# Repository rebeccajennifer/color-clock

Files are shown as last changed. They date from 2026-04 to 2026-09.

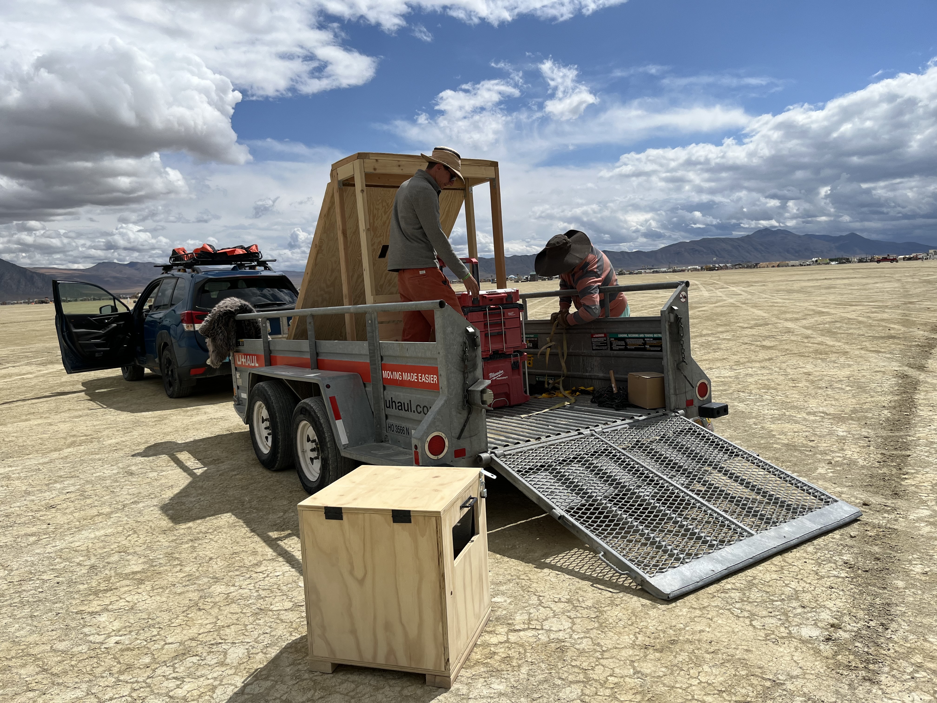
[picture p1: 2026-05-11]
docs/slide-decks/2026-05-05__engineering-talk/07__deployment__eng-talk/on-site-install__eng-talk/IMG_2247.jpeg

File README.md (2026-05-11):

# ColorClock

## Code Location

The code base is contained in the Arduino directory located at
[./sw/arduino/color-clock-driver](./sw/arduino/color-clock-driver).

## Hardware

The project was designed using an `MKR1010` Arduino board that
interfaces with a real time clock module to keep accurate time.

### Wiring Diagram



## Documentation

The blog about this project can be found
[here](http://rebeccarashkin.com/color-clock).

A slide deck outlining the hardware and software design:
[here](./docs/slide-decks/2026-05-05__engineering-talk/color-clock-design__20260508.pdf)

## Description

Version 1 of ColorClock was an art piece displayed at Burning Man in
2024. The piece was a minimalist lean-to shade structure, housing a
2.5 ft diameter light display at its core. Within, a bench invited
participants to rest just above the playa. The light display, crafted
with concentric circles, marked the current time, providing nuanced
granularity such as the hour and minute. A user-controllable central
light introduced an element of interactivity. With a control panel,
the participant could manage cycle time and spectrum hues, enhancing the
understanding of the piece. ColorClock, in its simplicity and
interactivity, prompts contemplation on the temporal interplay of light
against the expansive backdrop of the playa landscape.

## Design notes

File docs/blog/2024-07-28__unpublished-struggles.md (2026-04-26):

This weekend I'm finally at the point that I wanted to be *last* weekend. After spending almost all of last Saturday soldering I learned that powering the Arduino with 12 volts no bueno 😵 But I knew I had some LM7805s (5 volt linear regulators) somewhere. Then a series of unfortunate events ensued...

- Soldered it too close to where the Arduino was supposed to go
- Battled with desoldering, surrendered the part
- Soldered in a new voltage regulator
- Realized I soldered it in backward
- Added new wires to make it work
- Plugged in the wrong Arduino board because it had the same footprint
- Realized level shifter wasn't working
- Battled with desoldering the headers from the component
- Gave up and soldered on longer pins
- Wired everything and found the on board buttons weren't working when the lights were on
- Fried my Arduino board while debugging

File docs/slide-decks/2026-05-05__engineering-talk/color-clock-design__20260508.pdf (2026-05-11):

# ColorClock

## Tell time through color

Introduction
Color Foundations
System Overview
Time Controller
Light Display
User Interface
Circuit Board Evolution
Deployment
Final Thoughts

# Introduction

What is ColorClock?

_____________________________

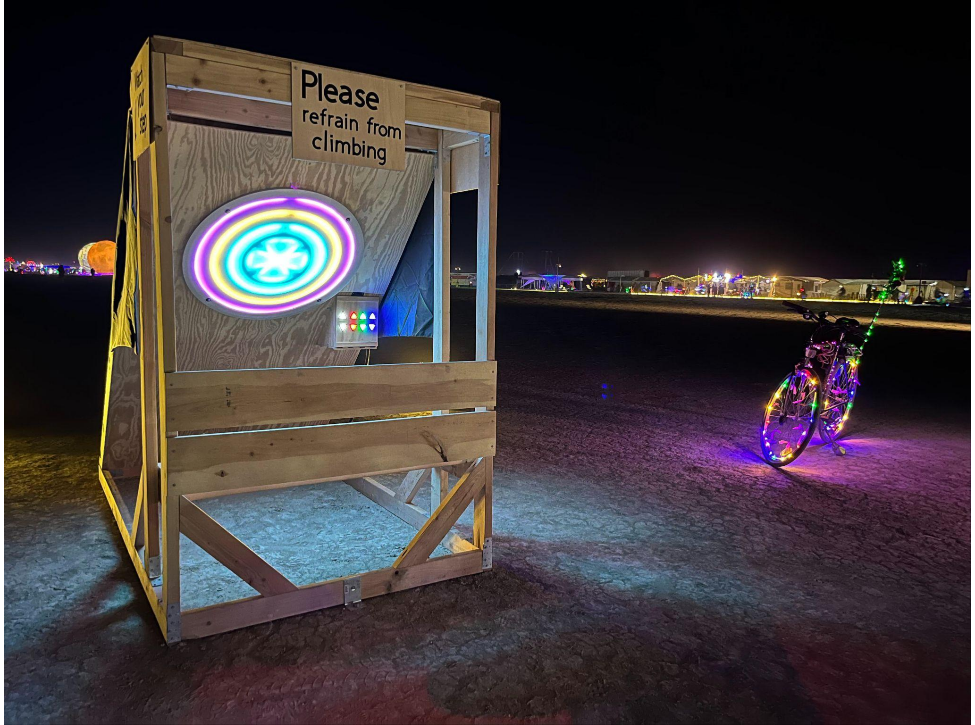
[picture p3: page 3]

## Software Prototype 2020

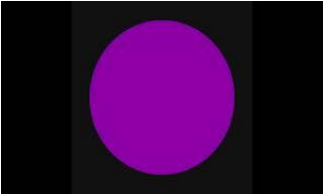
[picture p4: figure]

- | Built with | Processing:
Java-based language
for digital art
- Exercises color-time
mapping algorithm
- Cycle time: 6 seconds

## Module Prototyping 2022

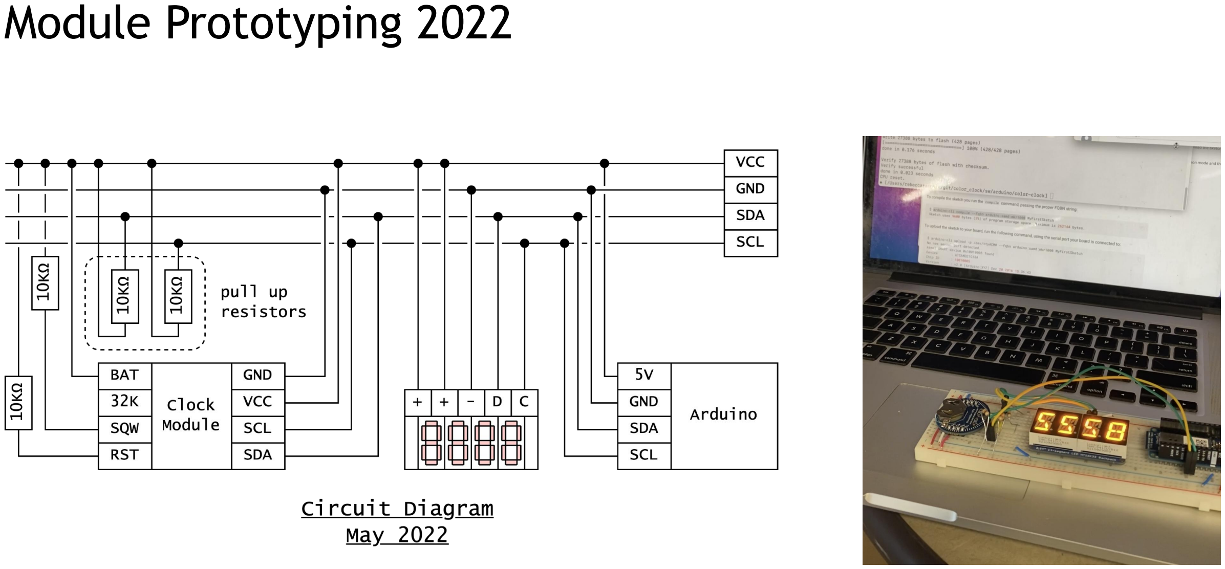
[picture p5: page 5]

Introduction
Color Foundations
System Overview
Time Controller
Light Display
User Interface
Circuit Board Evolution
Deployment
Final Thoughts

# Color Foundations

Mixing color with pigment
and light

_____________________________

## Pigment Primary Colors: Red, Yellow, Blue

## Light Primary Colors: Red, Green, Blue

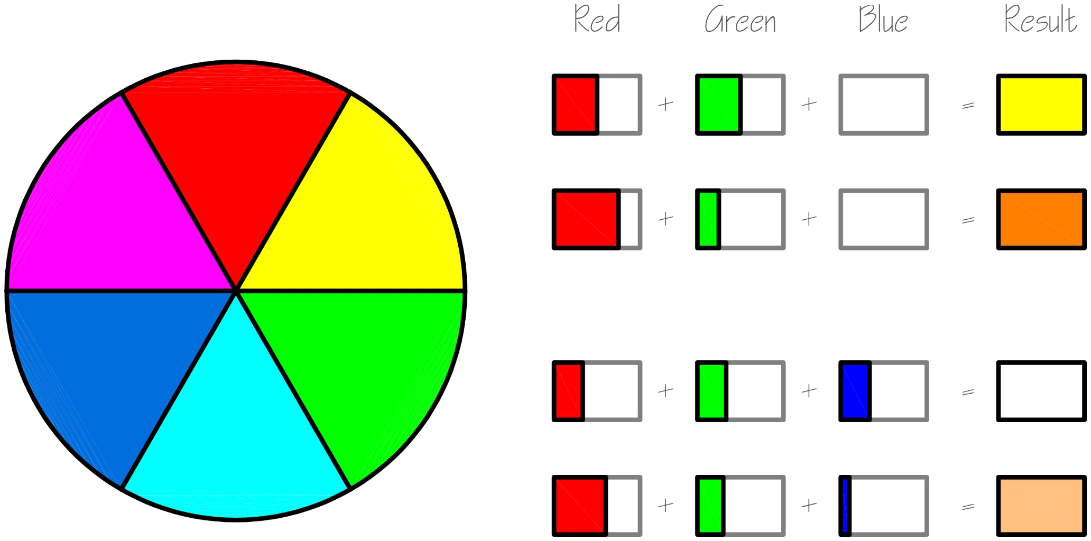
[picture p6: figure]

## Common Anode RGB LED - Light Orange = 4:2:1 R:G:B

Introduction
Color Foundations
System Overview
Time Controller
Light Display
User Interface
Circuit Board Evolution
Deployment
Final Thoughts

# System Overview

Top level design

_____________________________

## Light Display

## Use Case Diagram

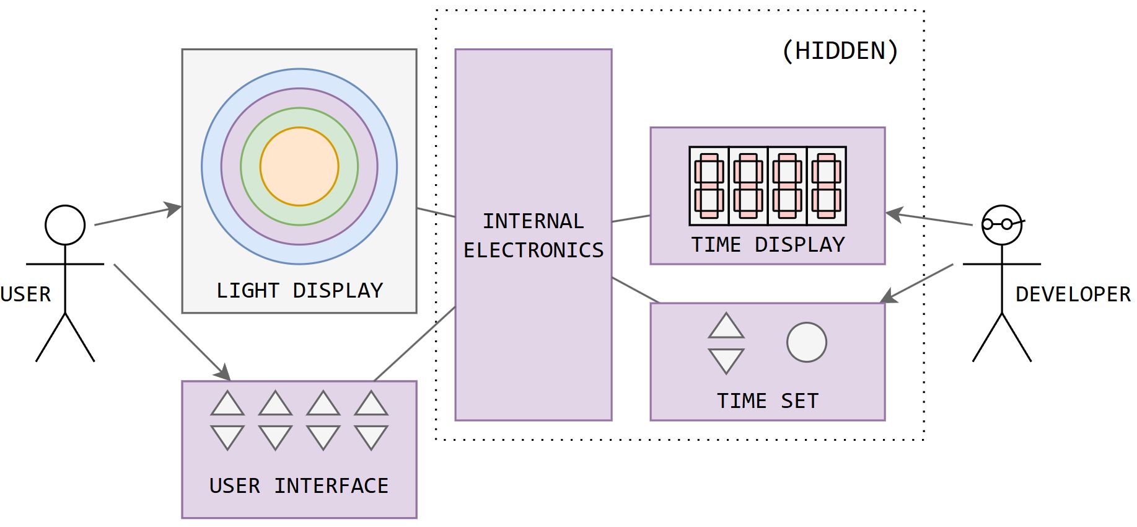
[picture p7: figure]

- User:
- Views light display
- Interacts with user
control interface
- Developer:
- Sets time
- Views time display
- Internal electronics
- I/O & control logic

## Top Level Hardware Design

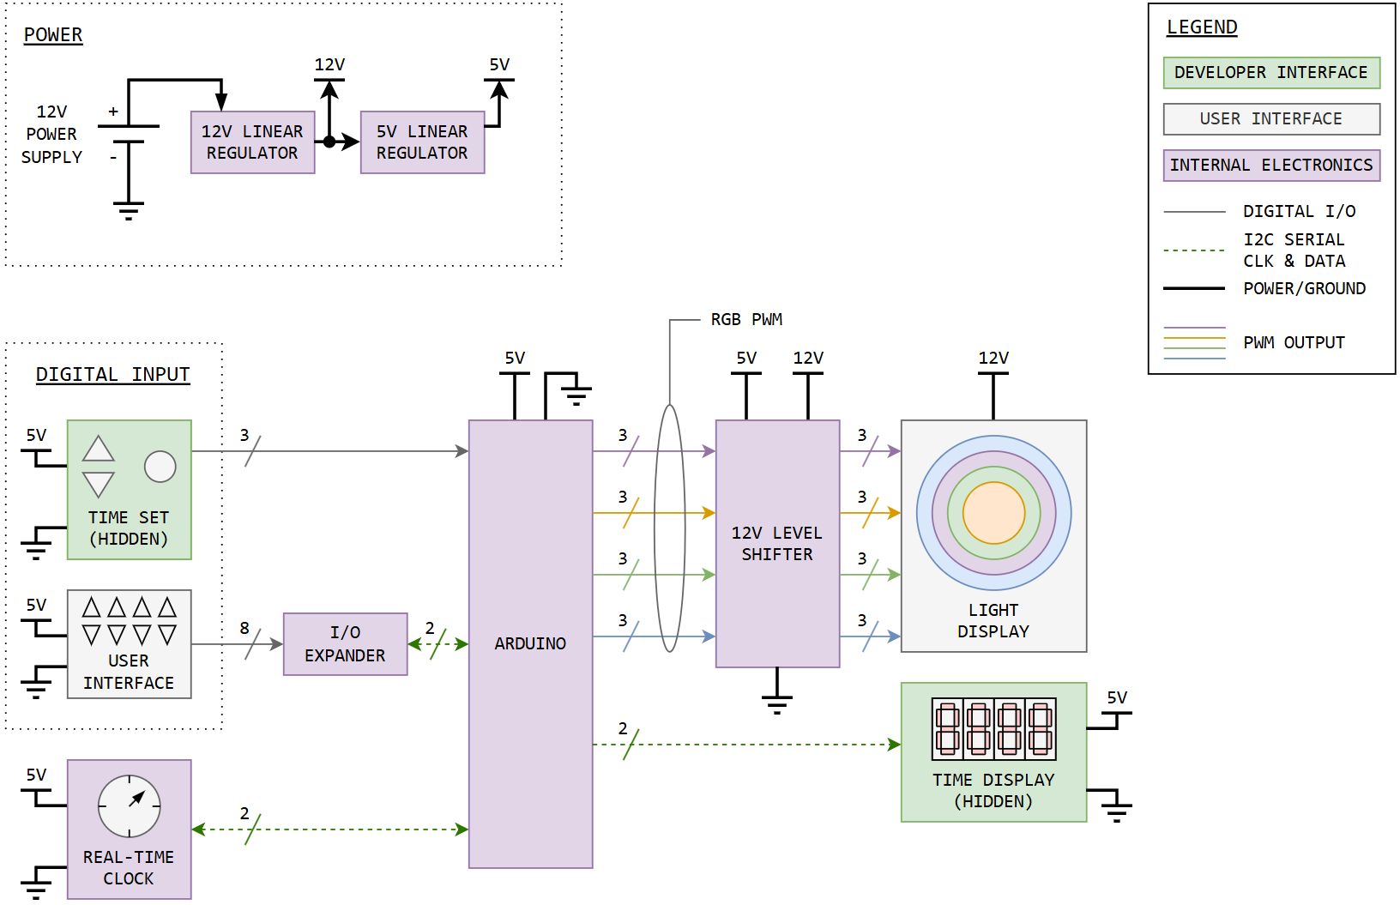
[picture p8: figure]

## Top Level Software Architecture

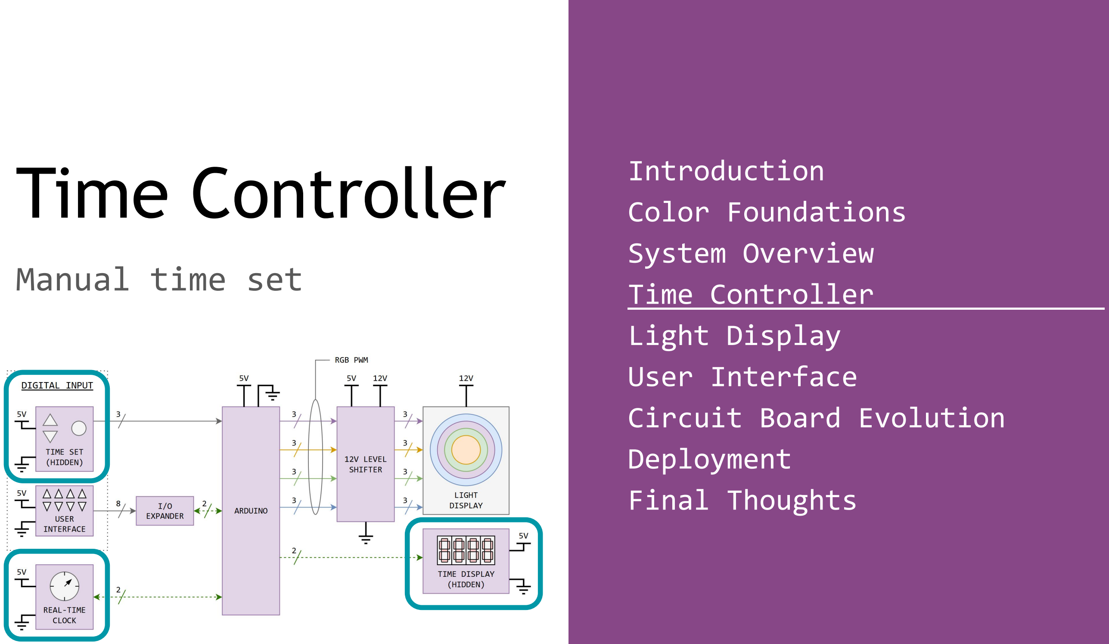
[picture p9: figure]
Introduction Color Foundations System Overview Time Controller Light Display User Interface Circuit Board Evolution Deployment Final Thoughts; Time Controller; Manual time set

## Time Controller Architecture

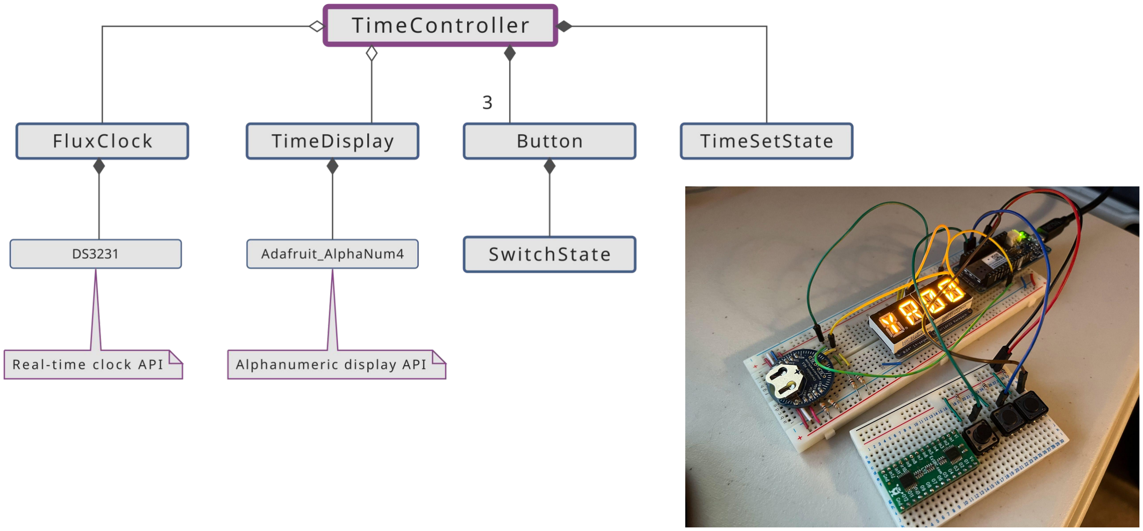
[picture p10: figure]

## State Diagrams

## Millisecond Granularity with Clock Module + System Time

- Real-time clock module - time resolution up to one second
- Millisecond precision is derived by combining:
- RTC time | (seconds)
- Arduino uptime (milliseconds since power-on)
- Hybrid approach enables higher resolution than the RTC alone
- Increased resolution -> supports smoother color transitions

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

_____________________________

## 4 ColorClocks; Color Shifts at Different Frequencies

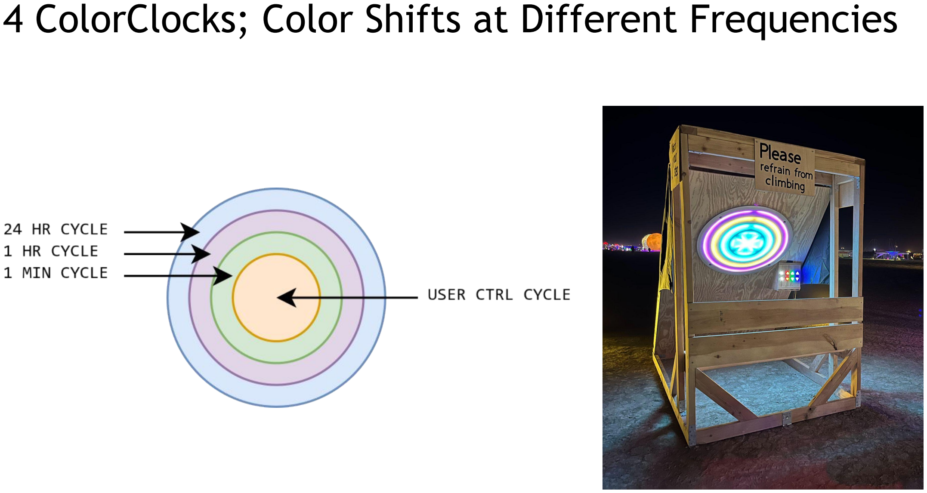
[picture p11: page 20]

## Level Shifter Scales Analog Output

- Input and output
reference voltages
- Used to scale a logic
level output, e.g. 3V to
12V
- Works as an amplifier in ColorClock

## Wiring Diagram Arduino to Level Shifter

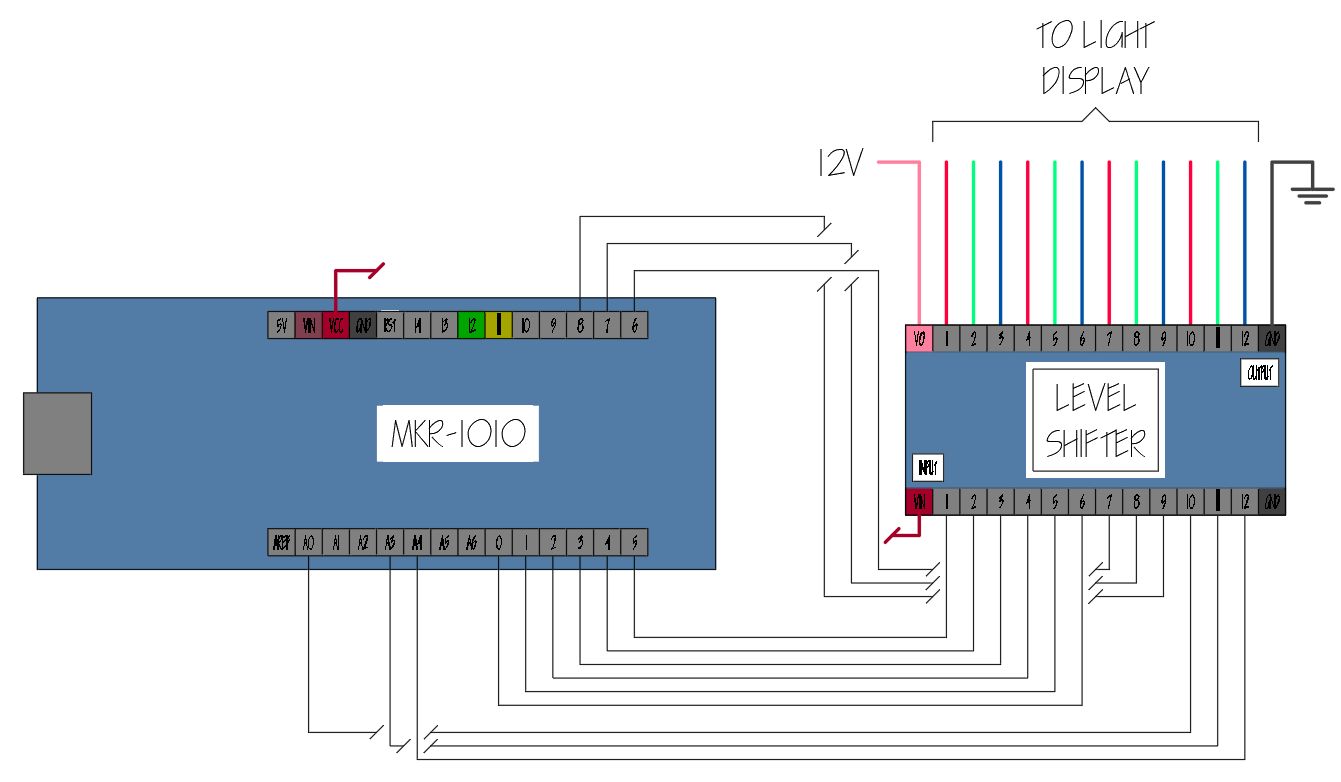
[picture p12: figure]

- Four ColorClock objects,
each with RGB from PWM
pins
- Microcontroller outputs
max 5V; LEDs require 12V
- Level shifter increases
output voltage from PWM
output pins

## ColorClock Class Diagram

## Colors Expressed as 24-Bit RGB Values

- Red, green, and blue
channels use intensity
values from 0–255
(0x00 → 0xFF hexadecimal)

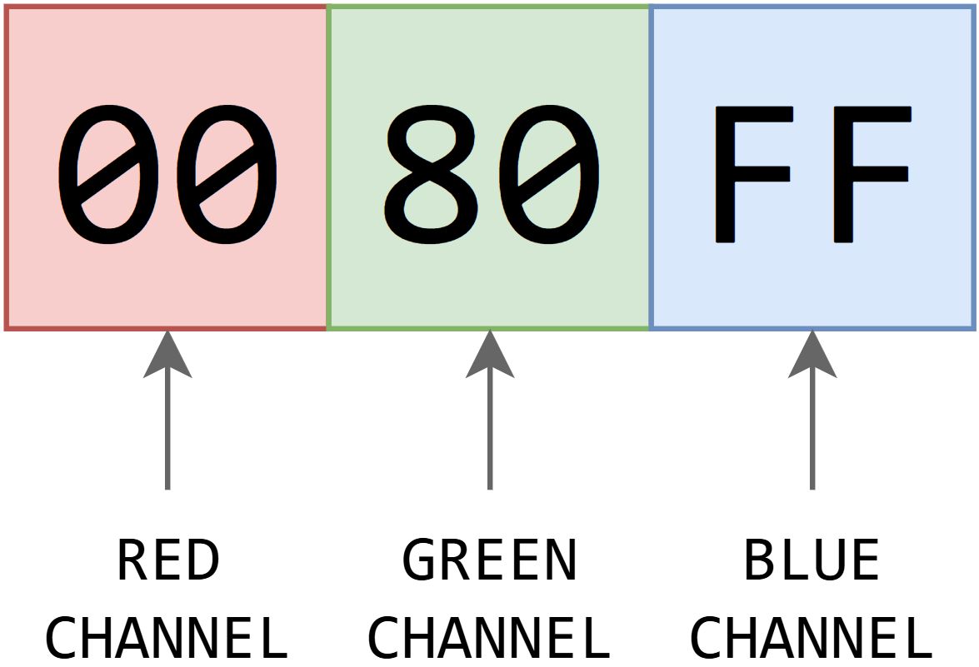
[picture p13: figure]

- PWM output interprets each channel value as a
fraction of full-scale
output (value / 255)

## Parallel Time-Color Mapping

- Two parallel arrays,
equal length
- One array stores colors
- One array stores the
corresponding times for
each color
color_selection | color_times
#FF0000 | 00:00

#FFFF00 | 04:00

#00FF00 | 08:00

#00FFFF | 12:00

#0000FF | 16:00

#FF00FF | 20:00

## Color Mapping Data Flow

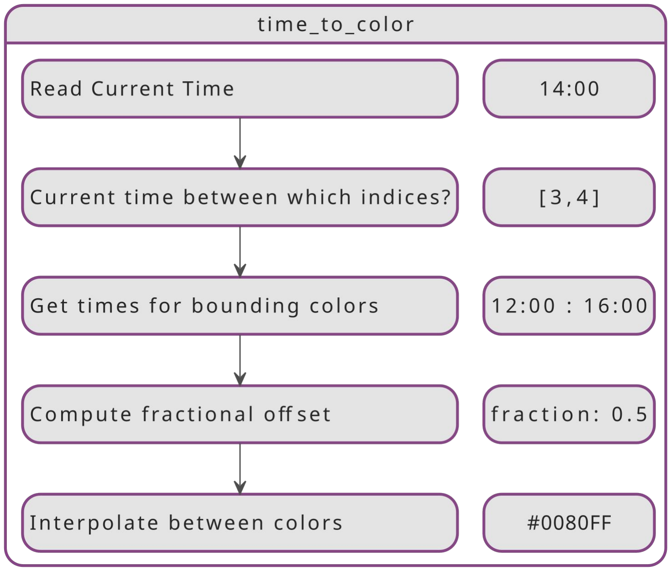
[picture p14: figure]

## Color Update Timing Testing

Color Updates Every Second | Color Updates Every Millisecond

Cycle Times: Top-6s, Middle-12s, Bottom-30s

## Light Display Construction

## Light Display Final Implementation

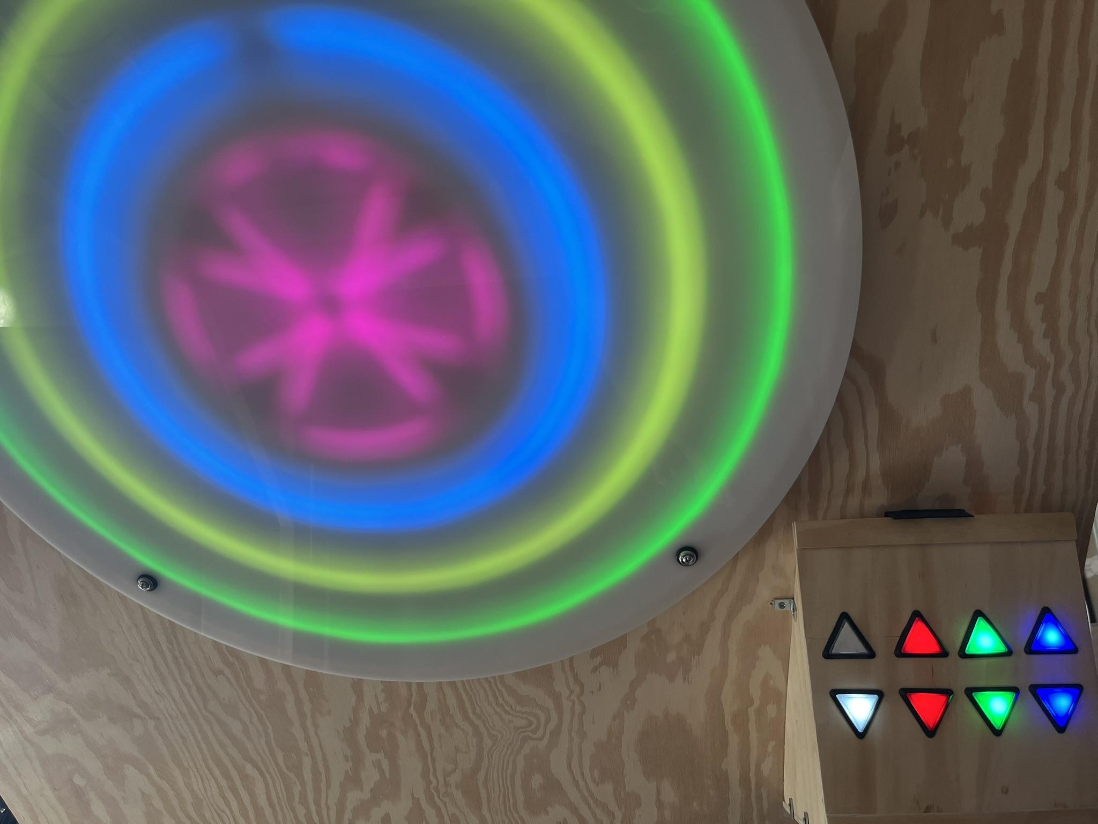
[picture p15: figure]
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

_____________________________

## User Input Control

Class Structure

## User Control Panel Prototyping

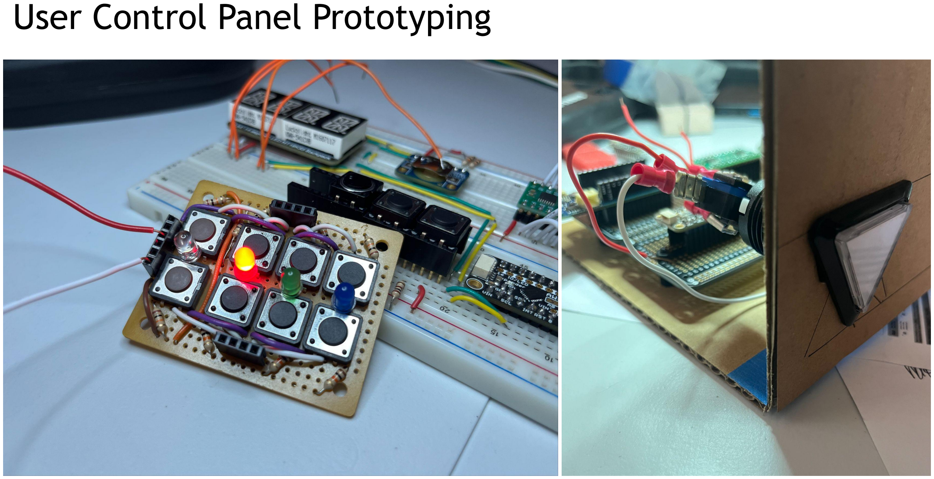
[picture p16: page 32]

## Final Implementation

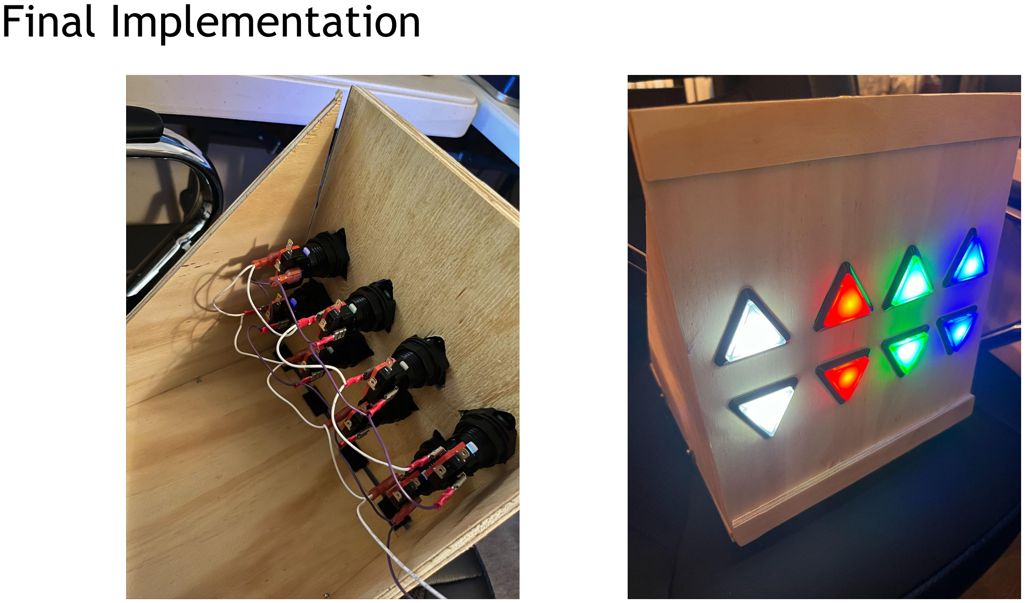
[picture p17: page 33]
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

# Circuit Board Evolution

From prototype to final
implementation

_____________________________

## Full Circuit Board Solderless Prototype

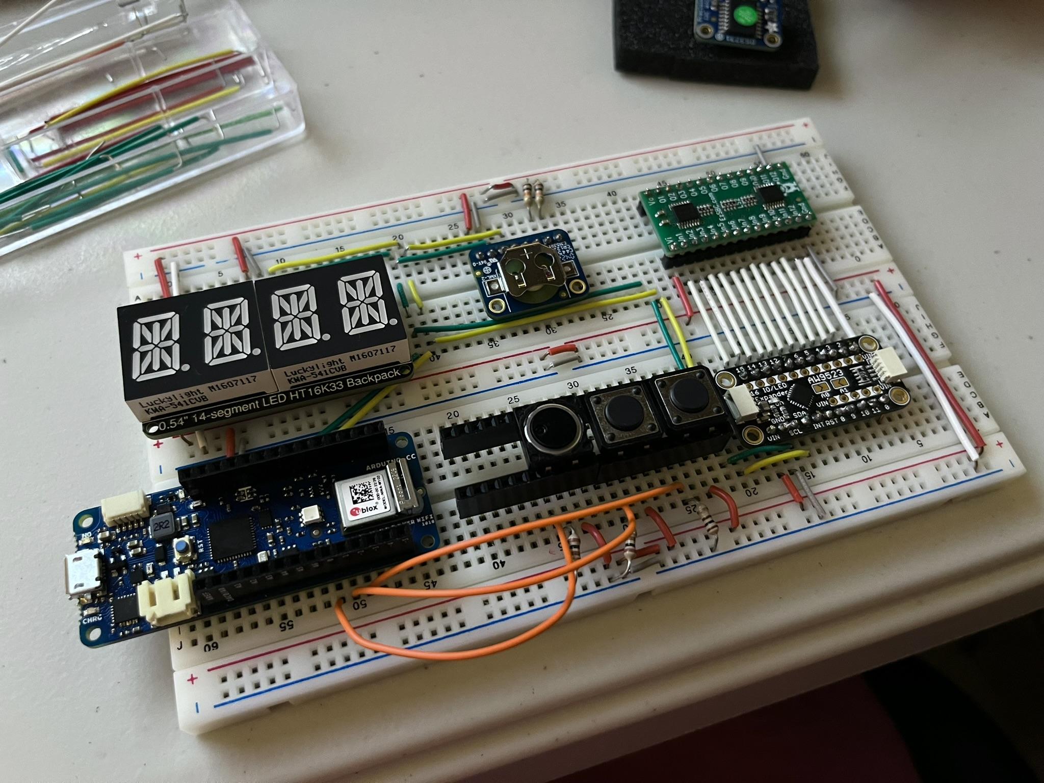
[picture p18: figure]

## Socketed Components for Rapid Replacement

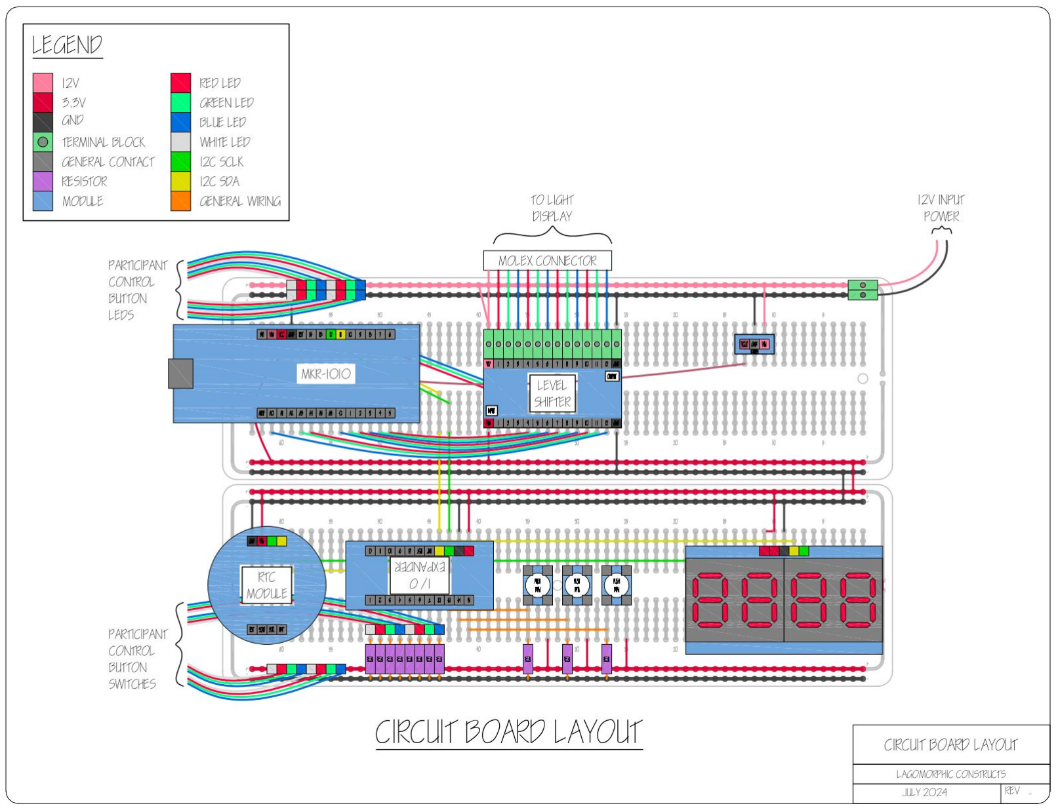
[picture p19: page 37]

## Final Implementation

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

_____________________________

# Infrastructure & Deployment

Structural implementation
and build

## Early Design Limitations

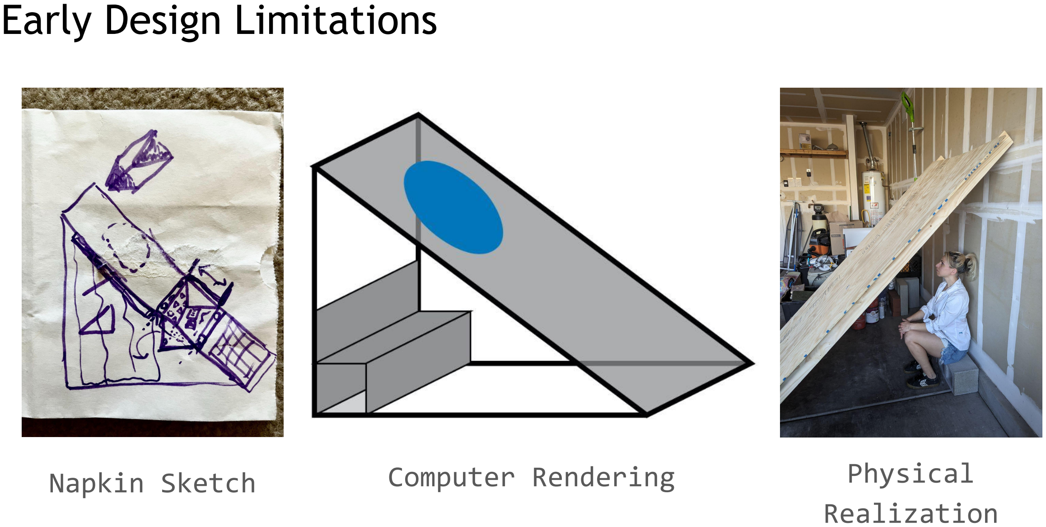
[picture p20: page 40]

Napkin Sketch | Physical Realization
Computer Rendering

## Extended Roof Design

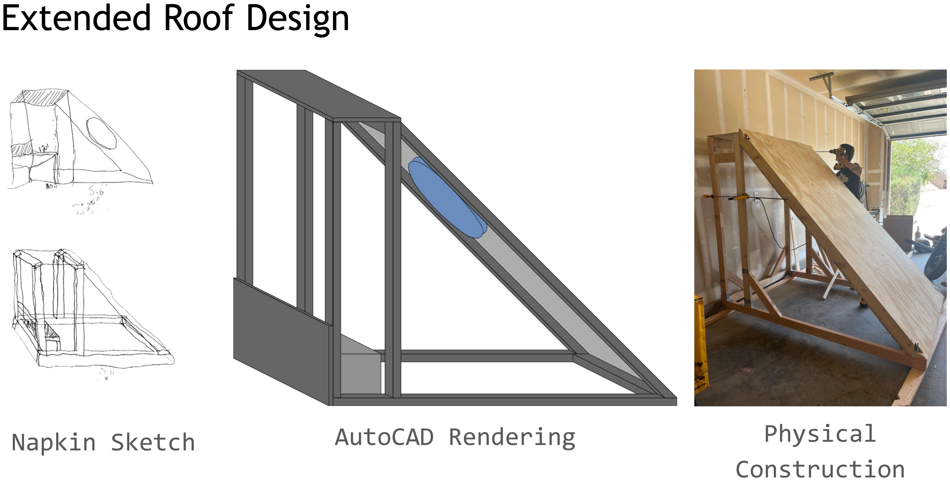
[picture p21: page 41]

Napkin Sketch | Physical Construction
AutoCAD Rendering

## Physical Assembly

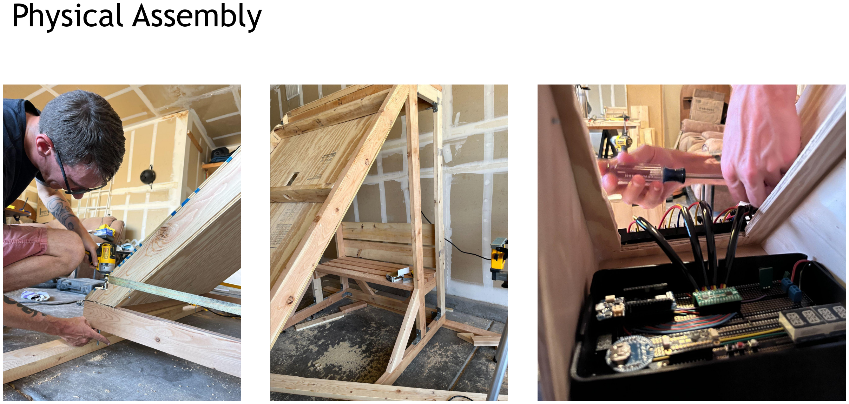
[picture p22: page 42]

## Solar Power Block Diagram

## Contingency Planning

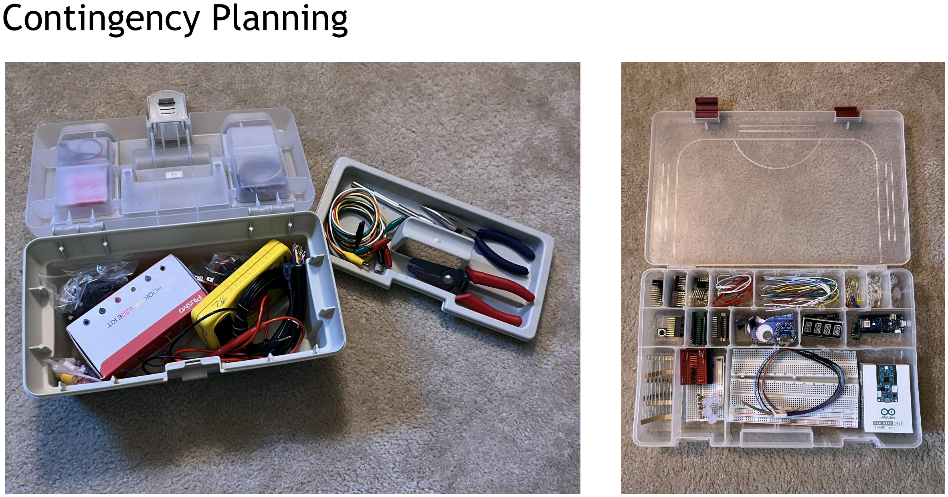
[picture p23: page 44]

## Build & On-Site Installation

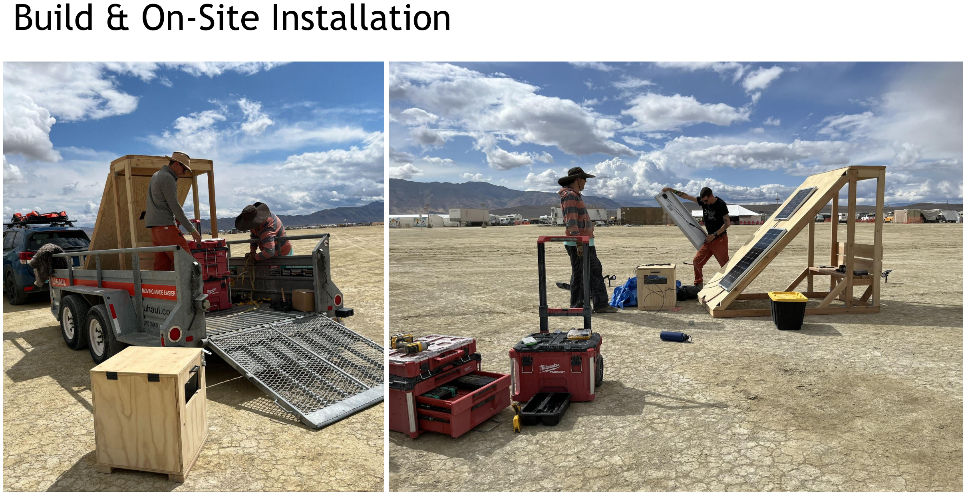
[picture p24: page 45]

## Final Result

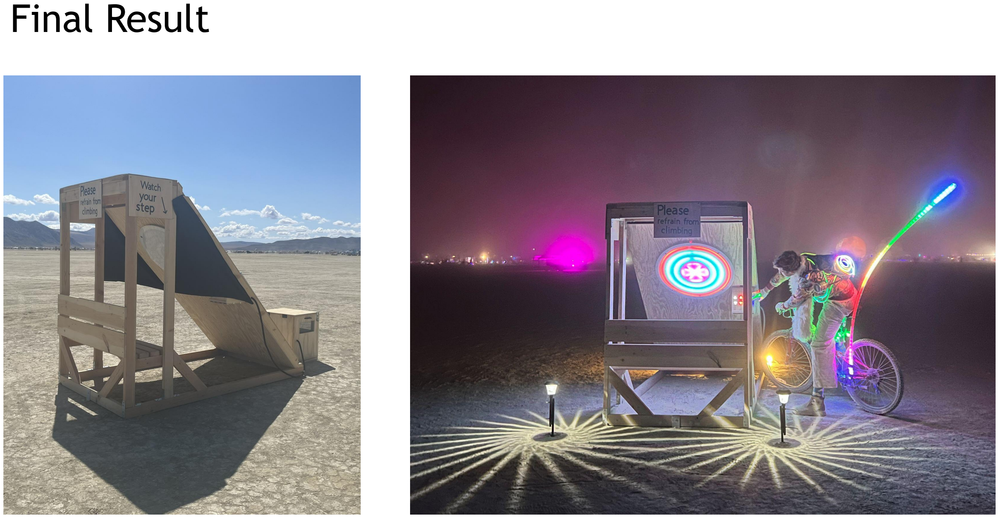
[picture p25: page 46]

Introduction
Color Foundations
System Overview
Time Controller
Light Display
User Interface
Circuit Board Evolution
Deployment
Final Thoughts _____________________________

# Final Thoughts

If I could do it again…

## ColorClock Version 2?

Issue | Proposed Improvement
PWM made wiring challenging, not enough I/O pins | Use addressable LEDs
Hand soldering wires is tedious | Design printed circuit board
User interface confusion | More intuitive user interface - a key perhaps?
Visual presentation | Improve visual aesthetic
Limited daytime visibility | Full enclosure?

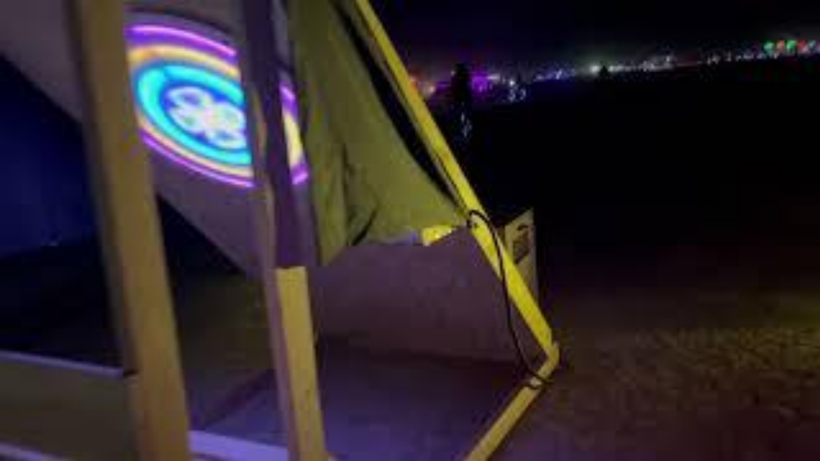
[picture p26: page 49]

## ColorClock Links

Source Code

github.com/rebeccajennifer/color-clock/tree/m ain/sw/arduino/color-clock-driver

Website

rebeccajennifer.com/projects/color-clock

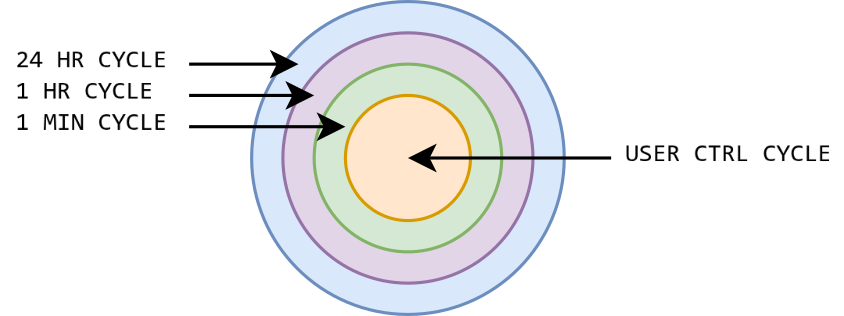
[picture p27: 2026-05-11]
docs/slide-decks/2026-05-05__engineering-talk/02__system-overview__eng-talk/light-display__20260426.png

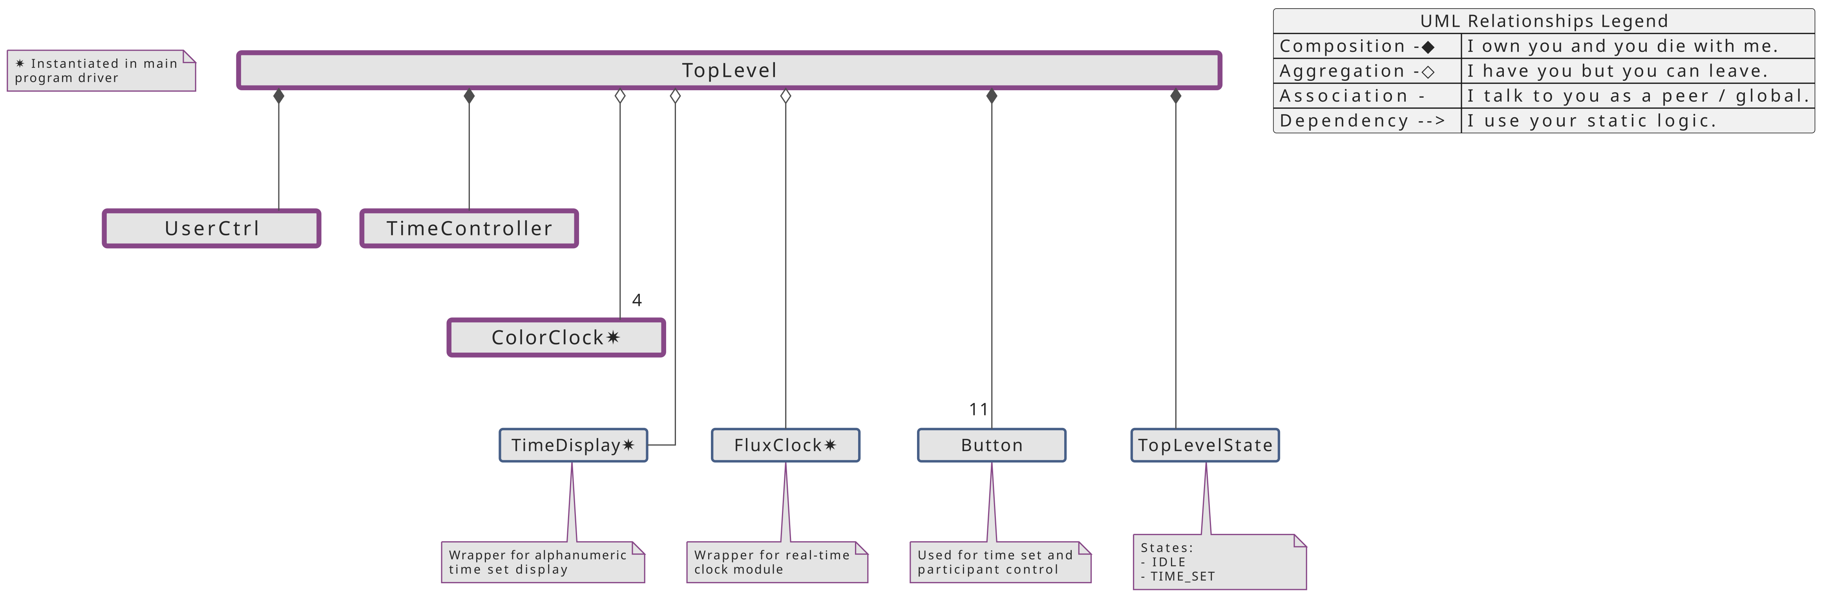
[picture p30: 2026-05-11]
docs/sw-docs/plant-uml/bitmap-img__puml/0-class-top-level.png

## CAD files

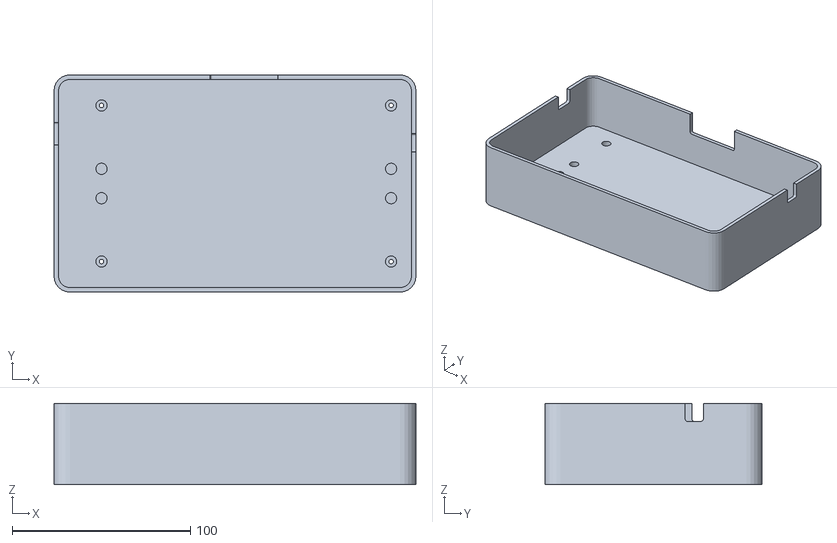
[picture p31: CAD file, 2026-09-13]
docs/imgs/acad/housing-home-display/housing-home-display-base__color-clock__2026-06-27.stl
203.2 x 121.9 x 45.7

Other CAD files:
docs/imgs/acad/housing-home-display/housing-home-display__color-clock__2026-06-27.dwg
docs/imgs/acad/housing-home-display/housing-home-display-base__color-clock__2026-06-27.dwg

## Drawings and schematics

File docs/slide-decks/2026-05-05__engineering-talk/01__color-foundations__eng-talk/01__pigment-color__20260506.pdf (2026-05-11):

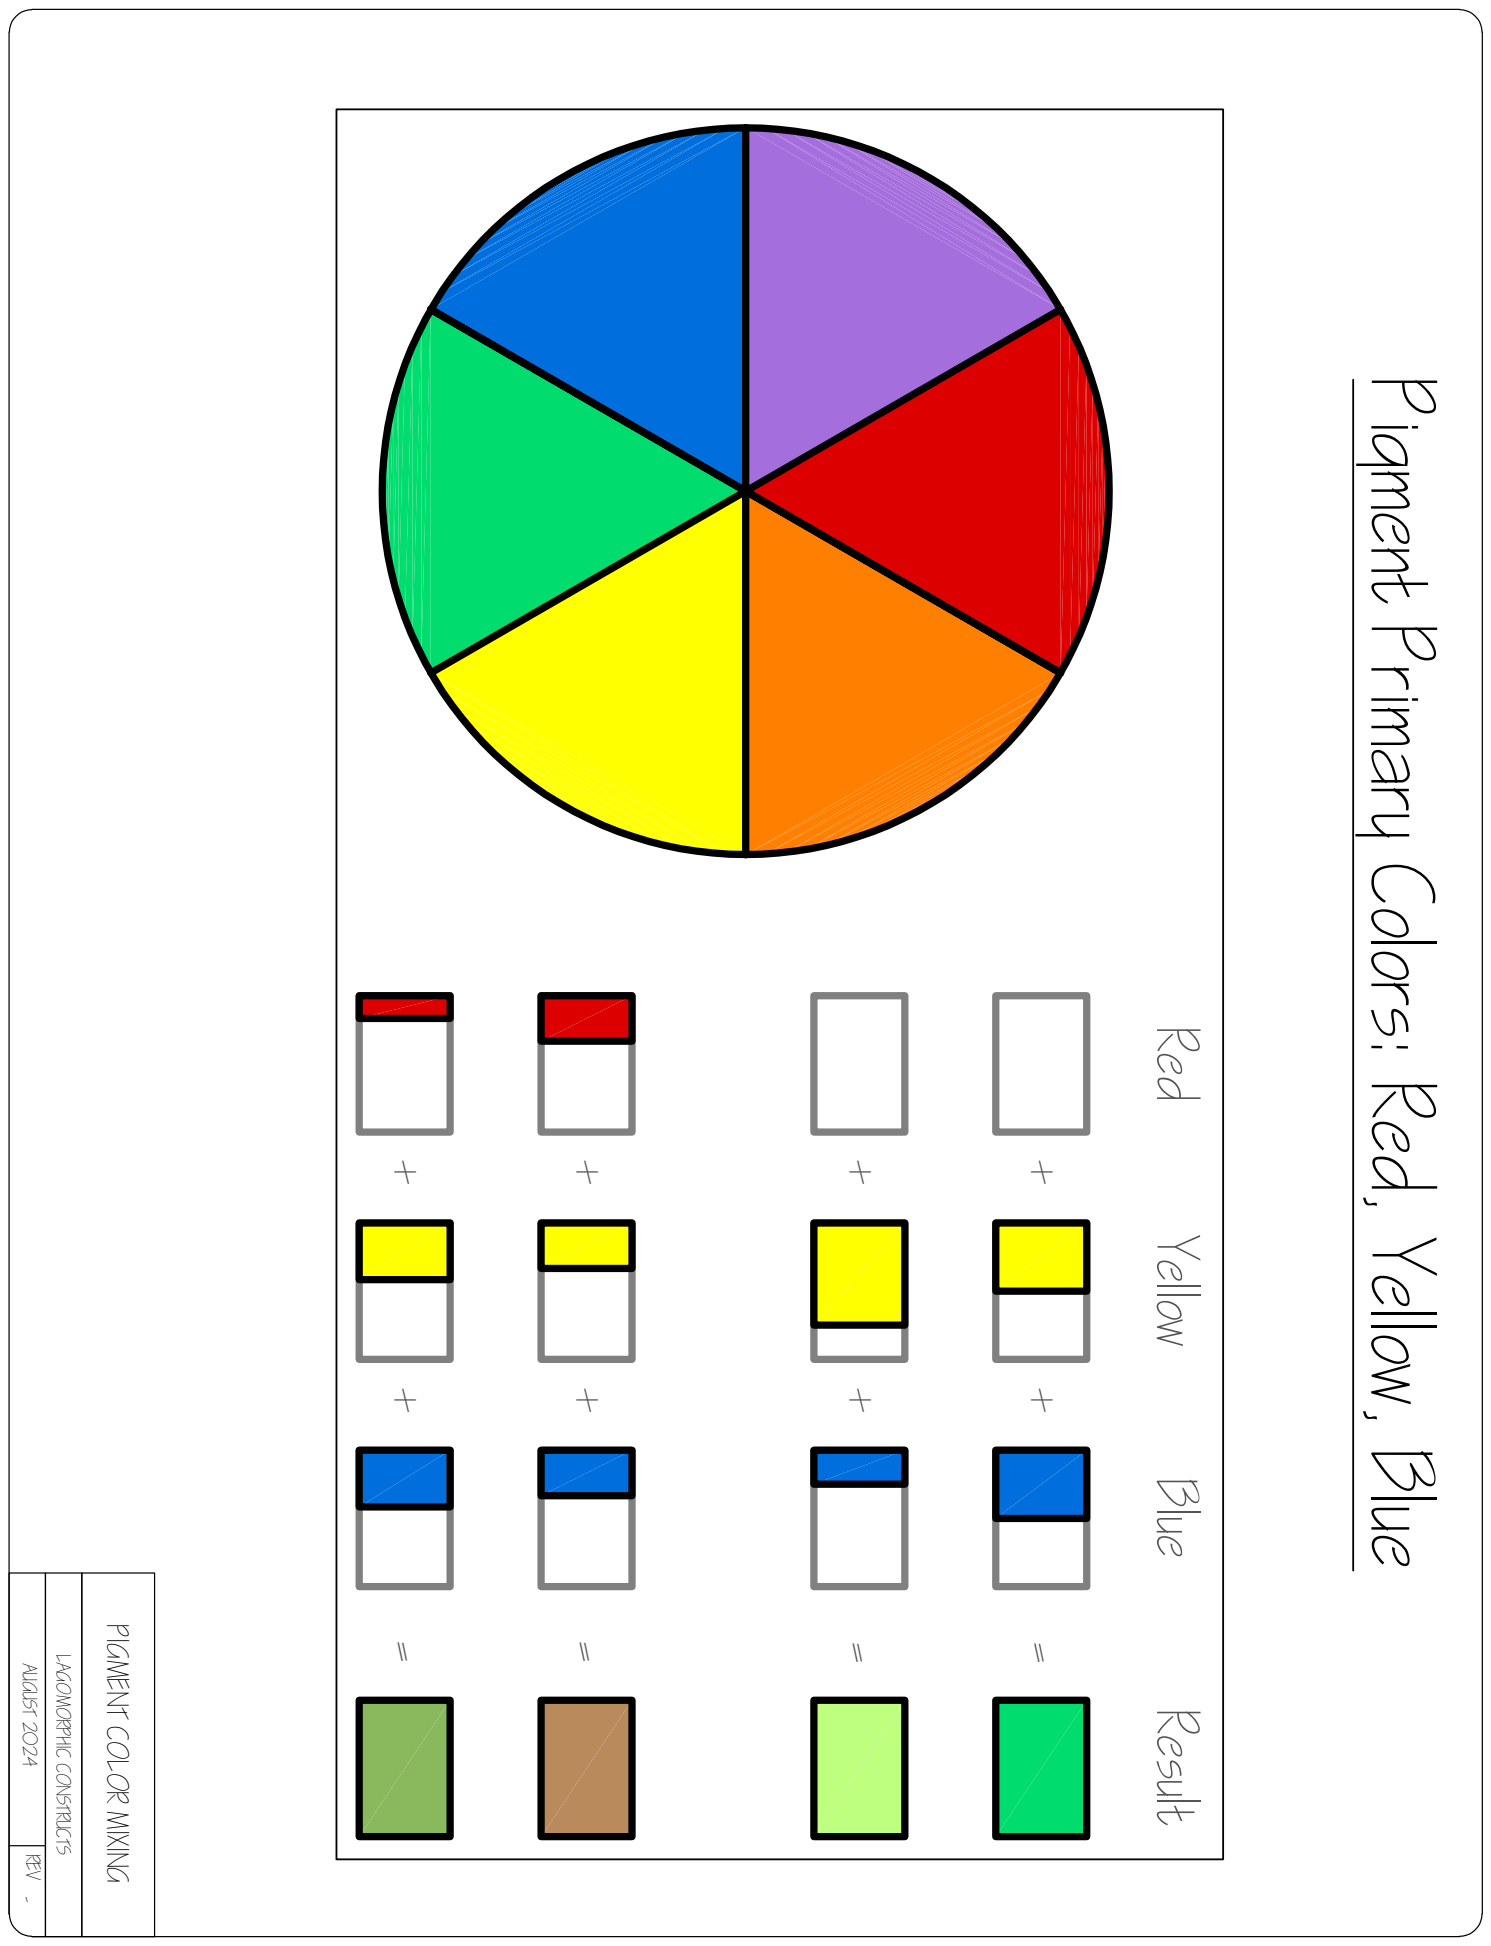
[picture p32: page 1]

REV LAGOMORPHIC CONSTRUCTS - AUGUST 2024 PIGMENT COLOR MIXING Pigment Primary Colors: Red, Yellow, Blue Red Yellow Blue Result ++ ++ == + + = + + =

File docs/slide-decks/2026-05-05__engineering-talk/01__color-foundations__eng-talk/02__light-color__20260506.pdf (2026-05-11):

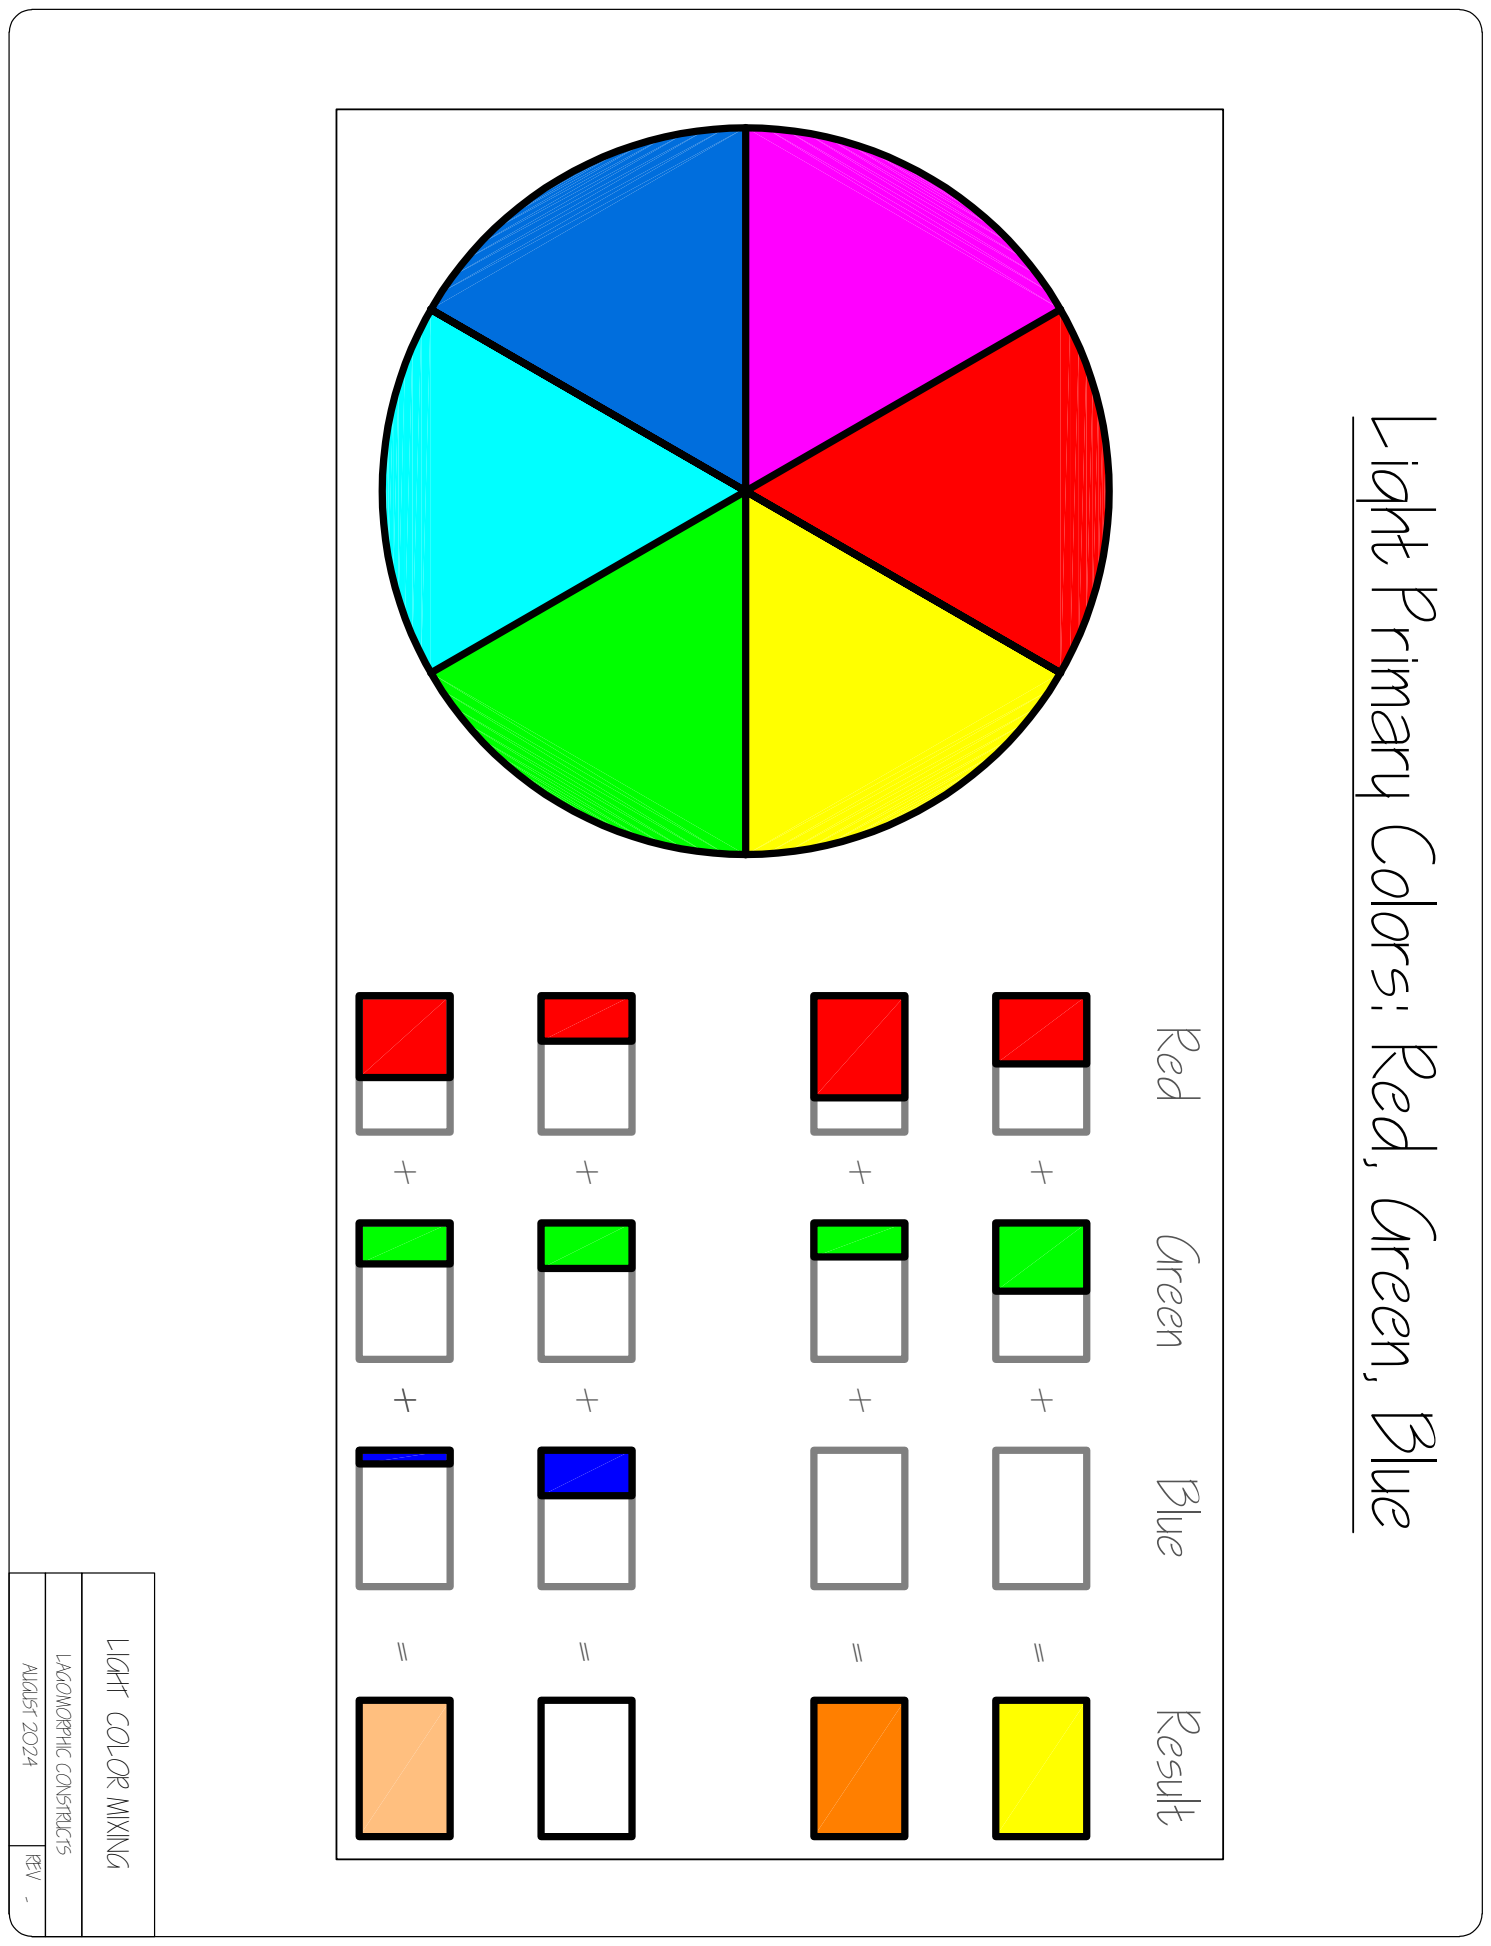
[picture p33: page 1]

REV LAGOMORPHIC CONSTRUCTS - AUGUST 2024 LIGHT COLOR MIXING Light Primary Colors: Red, Green, Blue Red Green Blue Result ++ ++ == + + = + + = +

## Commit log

2026-04-25 docs: Added button state logic
2026-04-26 refactor: Changed MomentarySwitch to Button, added note
2026-04-26 docs: Added program flow diagram for time_to_color
2026-09-13 docs: Added acad for home display housing
    [housing-home-display-base__color-clock__2026-06-27.dwg, housing-home-display-base__color-clock__2026-06-27.stl, housing-home-display__color-clock__2026-06-27.d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]
